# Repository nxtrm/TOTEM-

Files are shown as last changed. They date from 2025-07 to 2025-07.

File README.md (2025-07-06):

<picture align="center">
  <source media="(prefers-color-scheme: dark)" srcset="/docs/images/TOTEM_logo_dark.svg">
  <source media="(prefers-color-scheme: light)" srcset="/docs/images/TOTEM_logo_bright.svg">
  TOTEM logo
</picture>

<h1 align="center">T O T E M  + +</h1>

TOTEM++ is a 50 key column-staggered choc split keyboard. It is meant to be used with a [Seeed Studio XIAO nRF52840 BLE](https://www.seeedstudio.com/Seeed-XIAO-BLE-nRF52840-p-5201.html). 
This is an iteration on the TOTEM project by [GEIST](https://github.com/GEIGEIGEIST/TOTEM/tree/main) for those who like the design of the keyboard, but would like to have a few extra keys to ease the transition from larger keyboards.
[Here](https://www.hackster.io/geist/totem-a-tiny-splitkeyboard-with-splay-cb2e43) you can read about the process of making the original board.

***

## LAYOUT

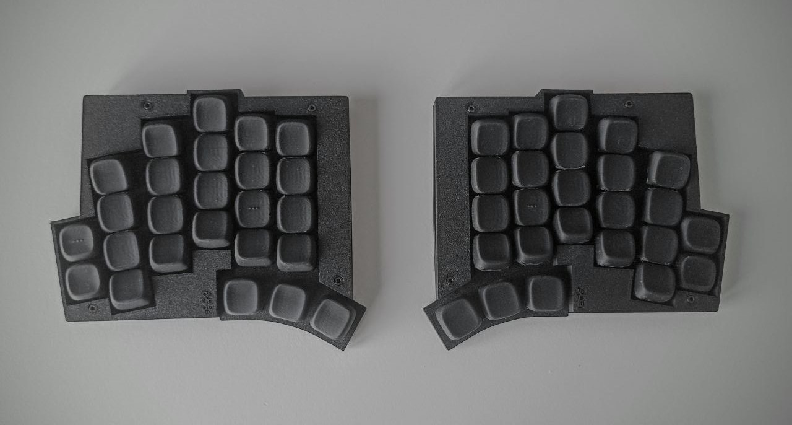
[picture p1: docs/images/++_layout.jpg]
TOTEM++ layout


***

## PCB

[Here](/PCB/) you can find the KiCad files for TOTEM++.

***

## CASE

You can use the TOTEM without a case, but [here](/case/) you can find one I made for it.

***

## BUILD GUIDE

The build guide for the TOTEM can be found [here](/docs/buildguide.md) (works for TOTEM++).

***

## FIRMWARE

[ZMK precompiled](/firmware/) or [ZMK source (recommended)](https://github.com/nxtrm/zmk-config) for the TOTEM (wireless using the XIAO BLE)

***

## PHOTOS

This is TOTEM++ in a matte black PLA case.

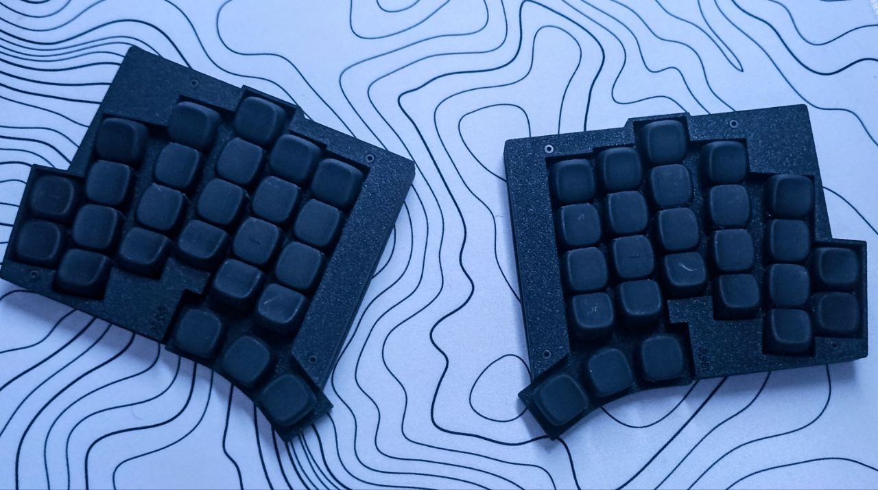
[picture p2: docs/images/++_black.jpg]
TOTEM matte black
\
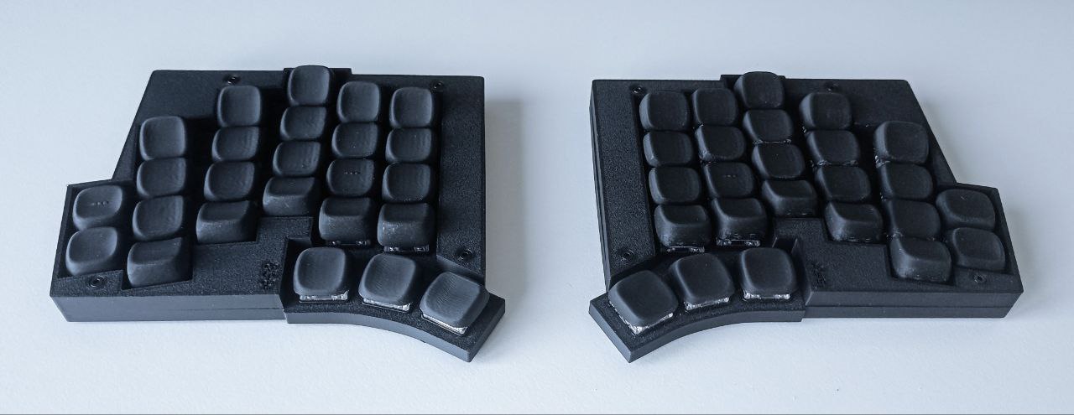
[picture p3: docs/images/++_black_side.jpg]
TOTEM matte black
\

***

### INSPIRATION

When i was researching the ergo keyboard market, I couldnt find a keyboard better looking (and cheaper to build) than the TOTEM, but with 38 keys, it was too overwhelming to migrate to it from my TKL keyboard.
To ease this transition, I added an extra row of keys (12 in total) to the design.

## CREDITS FOR THE ORIGINAL TOTEM PROJECT

[GEIST](https://github.com/GEIGEIGEIST) for creating the TOTEM keyboard.

#### PCB
- [Marco "Bob"](https://github.com/GroooveBob)

#### CASE
- [Freya](https://github.com/freya-irl)
- [Bubbleology](https://github.com/bubbleology)

#### FIRMWARE
- [Cem Aksoylar](https://github.com/caksoylar)
- [Grinnie](https://github.com/regicidalplutophage)
- [Alaa Saad Mansour](https://github.com/AlaaSaadAbdo)
- [pekudzu](https://github.com/pekudzu)

If you build a TOTEM I would be pretty happy to see some pictures. And if you want to leave the original creator of the keyboard (GEIST) a tip you can do this [here](https://ko-fi.com/geigeigeist) (but please don't feel pressured)

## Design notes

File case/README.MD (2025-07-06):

The case uses a 3-part design. The PCB is sandwiched between the plate and bottom, and the borders are screwed on top.
This design is easier to 3D-print and assemble, but has a thin seam visible between the plate and the borders.
There us no tenting version planned at this point, but the bottom part of the case can easily be swapped for another design.

You may find exported 3MF files for both sides of the keyboard [here](/3MF) or tweak and export each component manually from a complete build [here](/STEP/full.step)

***

## 3D Printing Guidelines

3D printing of the 3-part design is pretty straightforward. I printed all of the parts upside down on my A1 Mini with no supports, and they all turned out great. The case consists of straight walls and flat surfaces, which all 3d printers can manage at relatively high speeds without significant quality losses. 
The bottom plate can be printed at the lowest quality preset, as it is not visible and serves solely to stick silicone non-slip pads.
Print keycaps at an angle with supports to minimize the visibility of layer lines.

***

## Keycaps

I used the KLP Lame keycaps by [Braindefender](https://github.com/braindefender/KLP-Lame-Keycaps). Feel free to experiment with your own keycap choices or use a different configuration of KLP keycaps.
The keyboard shown on the pictures in this repository uses "Saddle Tilted", "Saddle" and "Saddle Homing" for the main 4x5 grid, "Normal" for the two side buttons and "Thumb" for the thumb cluster.

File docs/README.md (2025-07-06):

### The same buildguide can be found on the original TOTEM repository, as there is no difference in the way that the keyboard is built. Just stick to the WIRELESS TOTEM variant when possible.

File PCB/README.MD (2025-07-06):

# TOTEM PCB FILES

## MANUFACTURING
If you want to get the PCB made you need to generate GERBER and Drill files in KiCAD and upload them to a manufacturer's website.
GEIST recommends [JLCPCB](https://jlcpcb.com/), [Seeed Fusion](https://www.seeedstudio.com/fusion_pcb.html) or [PCBway](https://www.pcbway.com/), and I used JLCPCB, which had the most reasonable prices for me.
If you want the silkscreen in yellow [AllPCB](https://www.allpcb.com/online_pcb_quote_new.html) is a pretty affordable choice.

- generate the gerber and dril files [TUTORIAL](https://jlcpcb.com/help/article/How-to-generate-Gerber-and-Drill-files-in-KiCad-6)
- upload the ZIP file to the website of the manufacturer.
- sometimes the Gerber preview from JLCPCB can't display the PCB, even when the files are fine. In this case use these dimensions: 258.7mm * 94.35mm
- PCB Thickness 1.6mm
- 2 layers
- PCB Qty as much as you like. One PCB is a full keyboard.
- PCB Color Black (or any other color you like)
- No impedance control
- Surface Finish HASL(with lead) if you want the easiest soldering experience or LeadFree HASL.
- Remove Order Number Yes

***

## TAKE A DEEPER LOOK OR MODIFY 

You can download the project if you need to take a deeper look or modify something. You need the Open Source software [KiCad](https://www.kicad.org/) to open it.

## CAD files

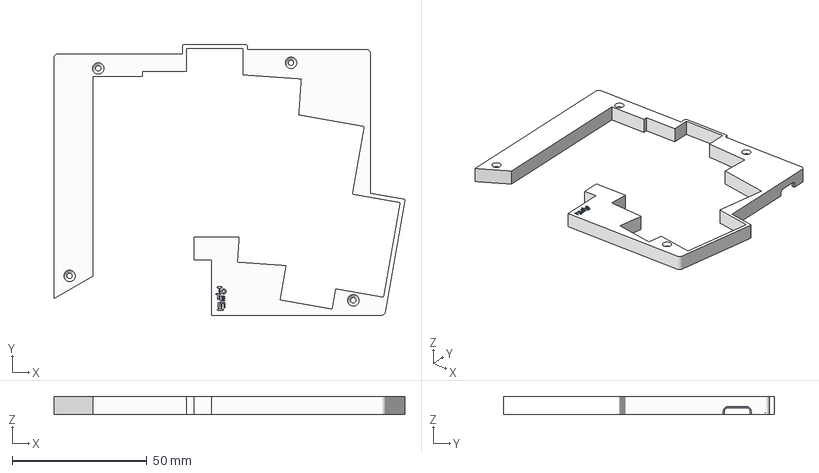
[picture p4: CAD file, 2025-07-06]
case/3MF/Border R.3mf
130.1 x 100.3 x 6.85 mm

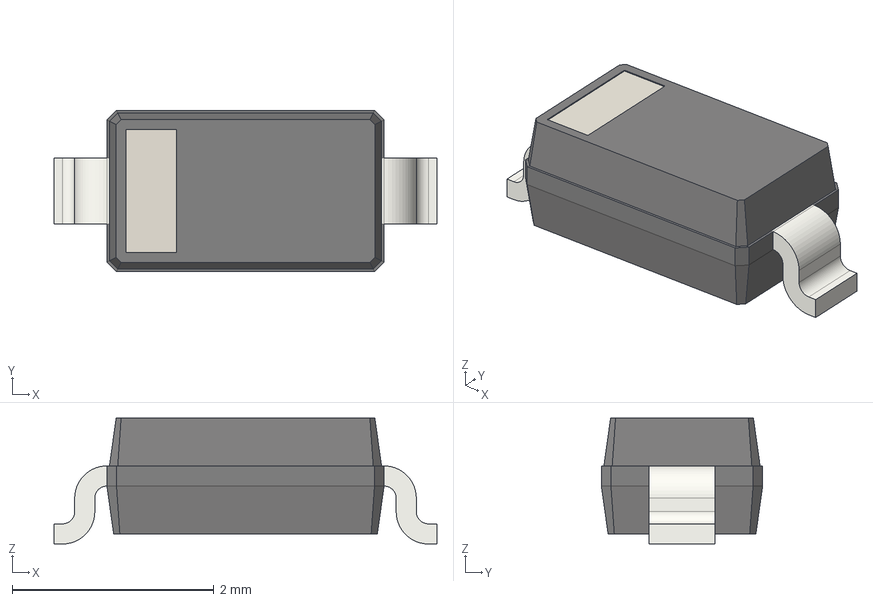
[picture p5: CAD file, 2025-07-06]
PCB/totem++/TOTEM3D/D_SOD-123.step
3.80 x 1.60 x 1.25 mm

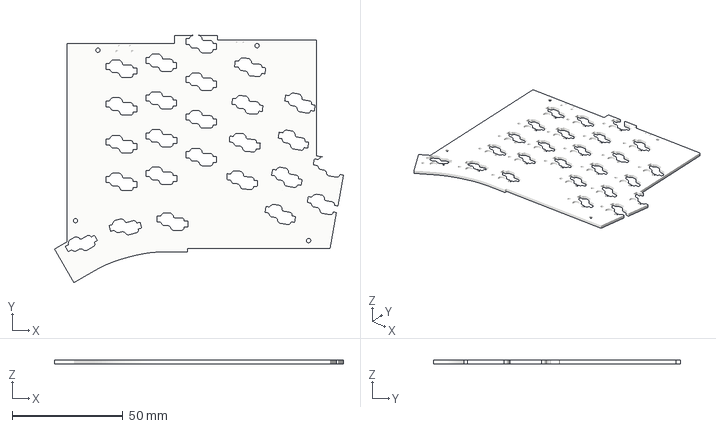
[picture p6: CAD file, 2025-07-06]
case/3MF/Bottom R.3mf
130.4 x 111.6 x 1.70 mm

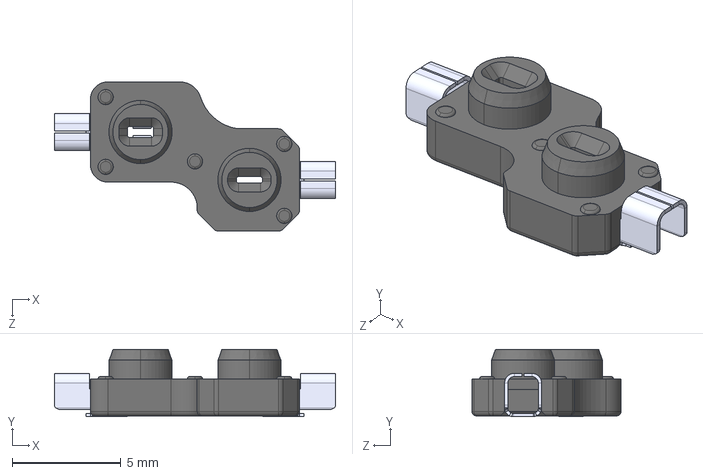
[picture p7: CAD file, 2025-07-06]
PCB/totem++/TOTEM3D/Kailh_socket_PG1350_optional.STEP
12.9 x 3.09 x 6.85 mm
pin x 2
socket

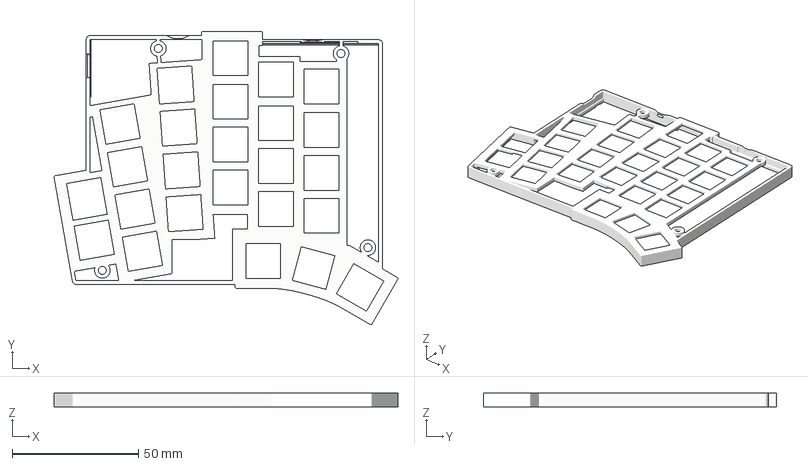
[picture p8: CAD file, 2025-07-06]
case/3MF/Plate L.3mf
136.3 x 116.2 x 5.65 mm

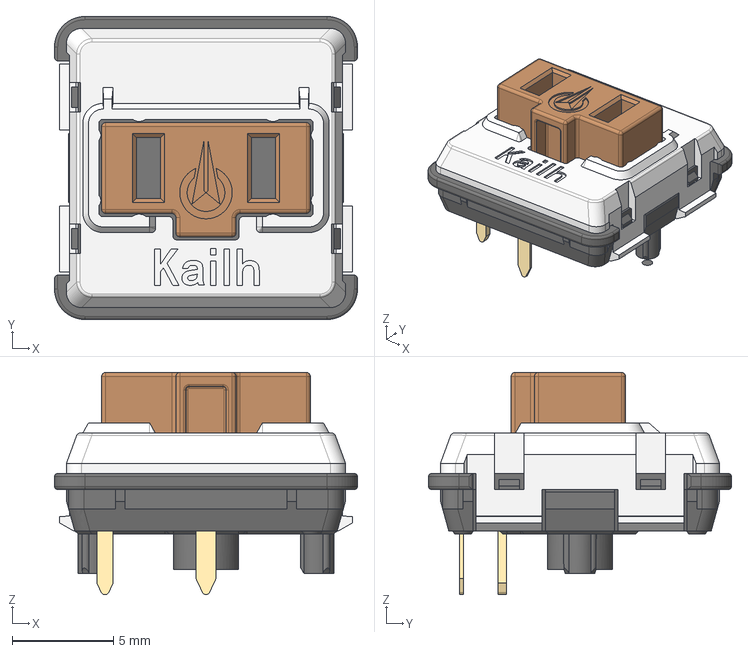
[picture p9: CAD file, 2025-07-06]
PCB/totem++/TOTEM3D/Kailh_switch_PG1350_optional.step
15.0 x 15.0 x 11.0 mm

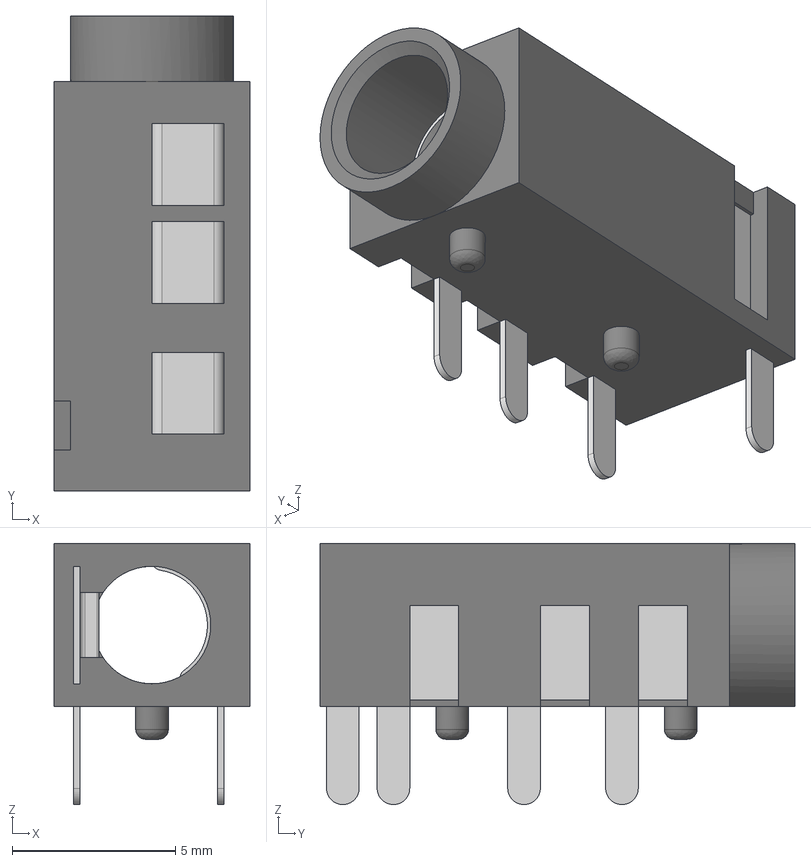
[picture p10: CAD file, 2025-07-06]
PCB/totem++/TOTEM3D/PJ320A.STEP
6.00 x 14.6 x 8.00 mm

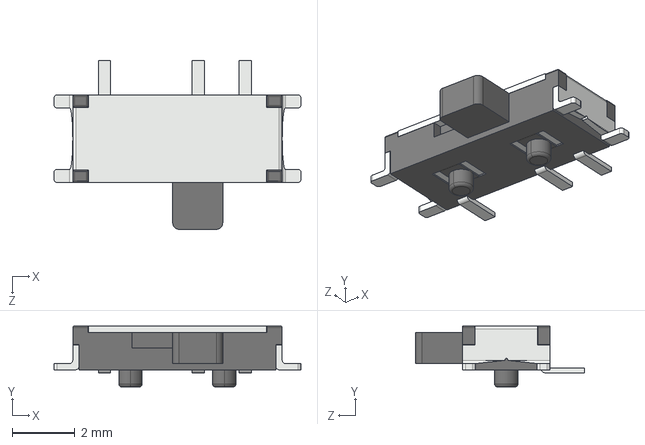
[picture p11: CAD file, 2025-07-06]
PCB/totem++/TOTEM3D/MSK12C02.STEP
7.90 x 1.95 x 5.39 mm

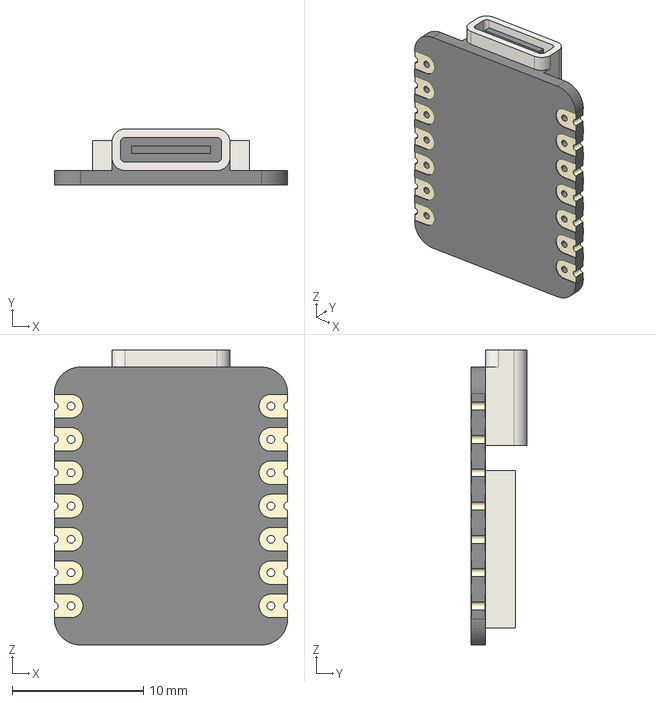
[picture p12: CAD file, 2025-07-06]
PCB/totem++/TOTEM3D/xiao-ble-tht.step
17.8 x 4.27 x 22.5 mm

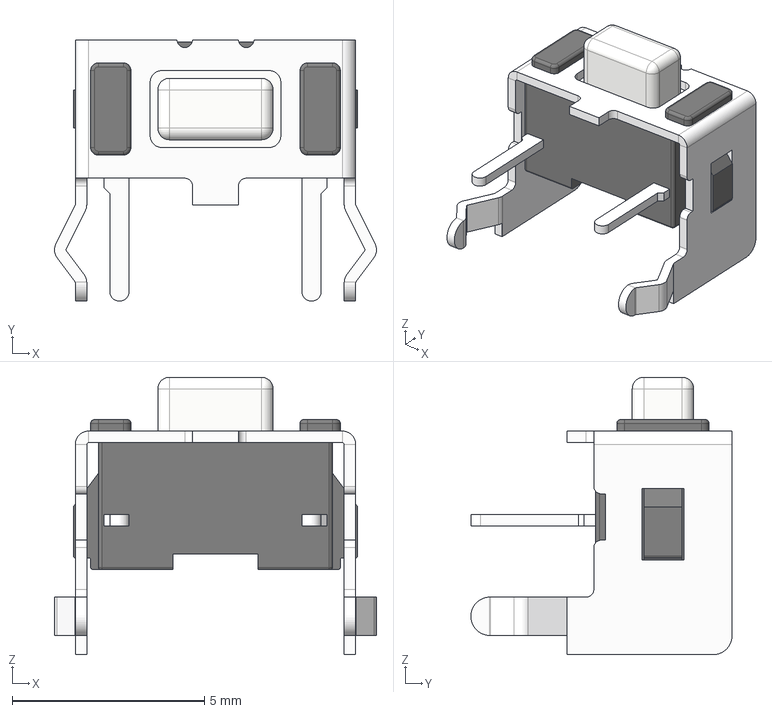
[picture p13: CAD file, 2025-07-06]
PCB/totem++/TOTEM3D/SW_SKHLLC.step
8.38 x 6.80 x 7.22 mm

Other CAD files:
case/3MF/Bottom L.3mf
case/3MF/Borders L.3mf
case/3MF/Plate R.3mf
